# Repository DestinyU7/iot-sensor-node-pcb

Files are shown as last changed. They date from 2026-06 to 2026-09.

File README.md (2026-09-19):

# IoT Sensor Node — Custom Arduino Shield PCB

A two-layer PCB designed from scratch in KiCad, fabricated at JLCPCB, hand-assembled, and running firmware that publishes live temperature telemetry to a cloud dashboard over Wi-Fi.

## Overview

University of Delaware coursework: **ELEG 298, ECE Design Challenges (Spring 2025)**. My first board taken end to end — schematic capture through layout, design rule check, Gerber generation, fabrication order, assembly, and bring-up.

The board is an Arduino Uno shield carrying a DHT20 temperature/humidity sensor interface, an ESP-01S Wi-Fi module on a UART link, status LEDs, and the supporting passives. Firmware reads temperature, classifies the trend as rising, falling or stable, signals that trend on two LEDs, and publishes each reading to an Adafruit IO feed over Wi-Fi.

<p align="center">
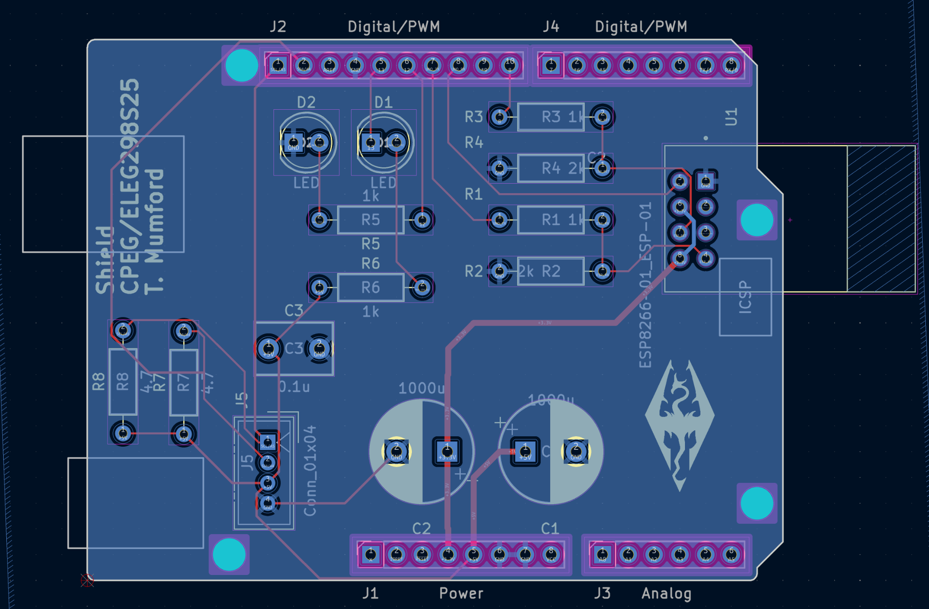
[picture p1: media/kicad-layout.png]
KiCad PCB layout
  
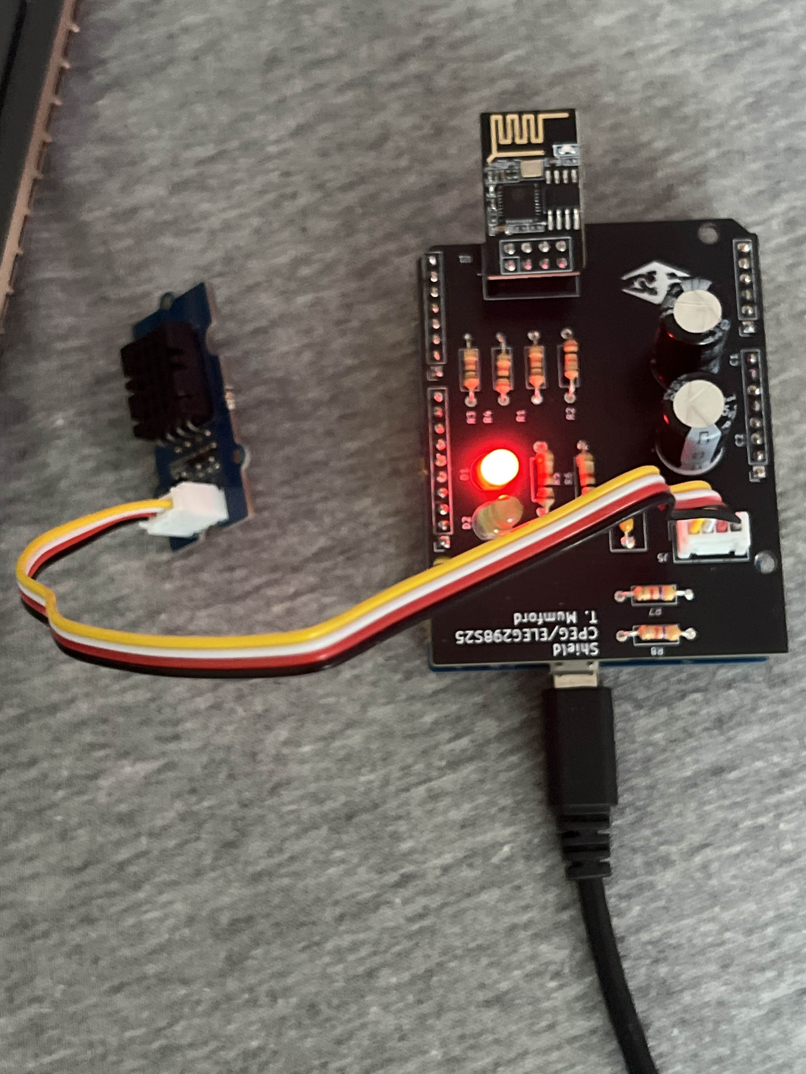
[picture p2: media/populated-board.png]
Fabricated board, hand-assembled and powered
  
</p>

<p align="center"><em>Left: the two-layer layout in KiCad. Right: the fabricated board hand-assembled, with the ESP-01S module fitted and a Grove sensor attached.</em></p>

## Hardware

| Function | Part |
|---|---|
| Host | Arduino Uno (shield form factor) |
| Wi-Fi | ESP-01S (ESP8266) over software UART |
| Sensor | DHT20 temperature / humidity (I²C, Grove connector) |
| Indicators | 2 × LED with 1 kΩ current-limiting resistors |
| Power | Bulk 1000 µF electrolytics + 0.1 µF decoupling |
| Level/pull-ups | 1 kΩ / 2 kΩ divider network, 4.7 kΩ I²C pull-ups |

Two copper layers (`F_Cu`, `B_Cu`), silkscreen on both sides, mounting holes, and an ICSP header passthrough.

## Software / Tools

- **KiCad** — schematic capture, PCB layout, DRC, Gerber and drill file export
- **Arduino C++** — `SoftwareSerial`, Grove DHT library
- **JLCPCB** — fabrication
- **Adafruit IO** — cloud feed and dashboard
- DigiKey-sourced BOM with costed line items

## Architecture

```mermaid
flowchart LR
    DHT["DHT20 sensor<br/>temperature + humidity"] -->|I2C| UNO
    UNO["Arduino Uno<br/>trend classifier"] -->|software UART<br/>9600 baud| ESP["ESP-01S<br/>ESP8266 Wi-Fi"]
    UNO --> LEDS["Red / green LEDs<br/>trend indication"]
    ESP -->|Wi-Fi| AIO["Adafruit IO<br/>temperature-feed"]
    AIO --> DASH["Cloud dashboard"]
```

The Uno drives the ESP-01S through a simple text command protocol over software serial (`wifi_ssid=`, `wifi_pass=`, `io_user=`, `io_key=`, `setup_io`, `setup_pubfeed=`, `send_data=`), with per-command timeouts and a hardware reset line to bring the module up cleanly at boot.

## Key Engineering Work

**Full PCB workflow, not just a schematic.** Component placement, two-layer routing with 45° trace angles and no right-angle bends, an 8 mil minimum line/space rule, silkscreen reference designators and polarity markers on both sides, DRC to zero errors and zero airwires, then Gerber + drill export and a fabrication-portal preview check before ordering. The Gerber set that was actually sent to the fab is in `hardware/gerbers/`.

**Designing for hand assembly.** The board mixes through-hole and SMD parts, with part choice and spacing driven by what could realistically be soldered by hand and reworked if wrong — a constraint that shaped the layout as much as the electrical requirements did.

**Trend classification instead of raw reporting.** Firmware compares each reading against the previous one with a ±0.1 °C tolerance band and tracks the last rising value, so the LEDs show direction of change rather than flickering on sensor noise, plus a stable-band indication between 22–24 °C.

**Reset sequencing.** The ESP-01S is held in reset at boot and released deliberately before any command is sent, which avoids the race where configuration commands are transmitted before the module's UART is listening.

## Testing / Validation

- **DRC and airwire check** in KiCad before Gerber export; fabrication-portal preview reviewed against the intended layout.
- **Continuity and power-rail checks** on the bare board before any active parts were fitted.
- **Incremental bring-up** — power, then LEDs, then sensor over I²C, then the ESP-01S link, then cloud publishing.
- **End-to-end verification** by watching readings appear on the Adafruit IO dashboard while warming the sensor by hand and confirming the LED trend indication matched.

## Repository Structure

```
firmware/           iot_sensor_node.ino - Arduino firmware
hardware/
  kicad/            schematic and two-layer board layout
  gerbers/          fabrication set sent to JLCPCB (copper, mask, silk, paste, drill)
docs/               final project design report
media/              layout render and photo of the assembled board
```

## Security Note

The Adafruit IO key and Wi-Fi credentials are **redacted** from the committed firmware (`IO_KEY = "REPLACE_WITH_ADAFRUIT_IO_KEY"`). Supply your own credentials to run it. No live key appears anywhere in this repository or its commit history.

## What I Learned

The layout was where the real learning was. A schematic that passes electrical rules can still be a board that is painful to assemble, hard to probe, and awkward to mount — trace angles, part spacing, silkscreen legibility and test-point access are decisions you only appreciate once you are holding the fabricated board with an iron in your hand.

Ordering it was the other half. Once Gerbers are submitted there is no undo, which forces a much more careful review pass than any purely simulated assignment ever did.

## Academic Context

University of Delaware, ELEG 298 — ECE Design Challenges, Spring 2025. Design, layout, firmware and assembly are my own work.

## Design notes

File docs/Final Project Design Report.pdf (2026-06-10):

### Final Project Design Report

### Timothy Mumford

5/16/2025

### 1. Description of the Circuit Functionality

For this project, I took the core of a Seeeduino and used it to build a custom PCB in KiCad. The main idea was to make a small device that could tell me if temperatures were getting too high while I was gaming on my PC. I used one of the sensors from the Grove kit (a temp sensor), and based on the readings, it lights up a red LED if things are getting too hot, and a green LED when things are normal. It's a pretty simple visual indicator but good enough to keep me aware without needing to check software every time.

This project helped me get familiar with PCB design, and I also learned how to integrate Grove connectors and keep the circuit small and functional.

### 2. Schematics of the Circuit

### See the attached schematic Png generated in KiCad. It shows all the components like the ESP8266 module, LEDs, resistors, and Grove connector. Everything was kept minimal to keep

the board compact.

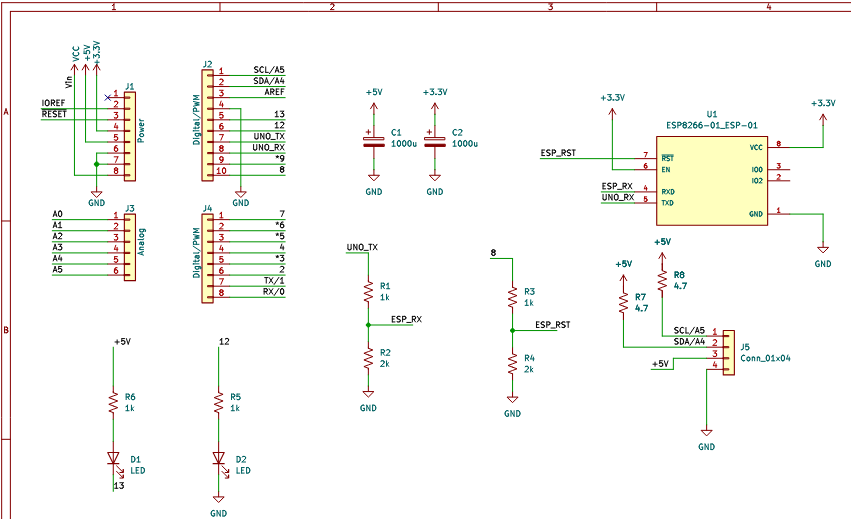
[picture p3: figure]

### 3. CAM Images (Manufacturing View)

### Top and bottom images of the PCB were exported from the KiCad 3D viewer. These show what

the finished board would look like. The layout was kept as neat as possible given the limited space.

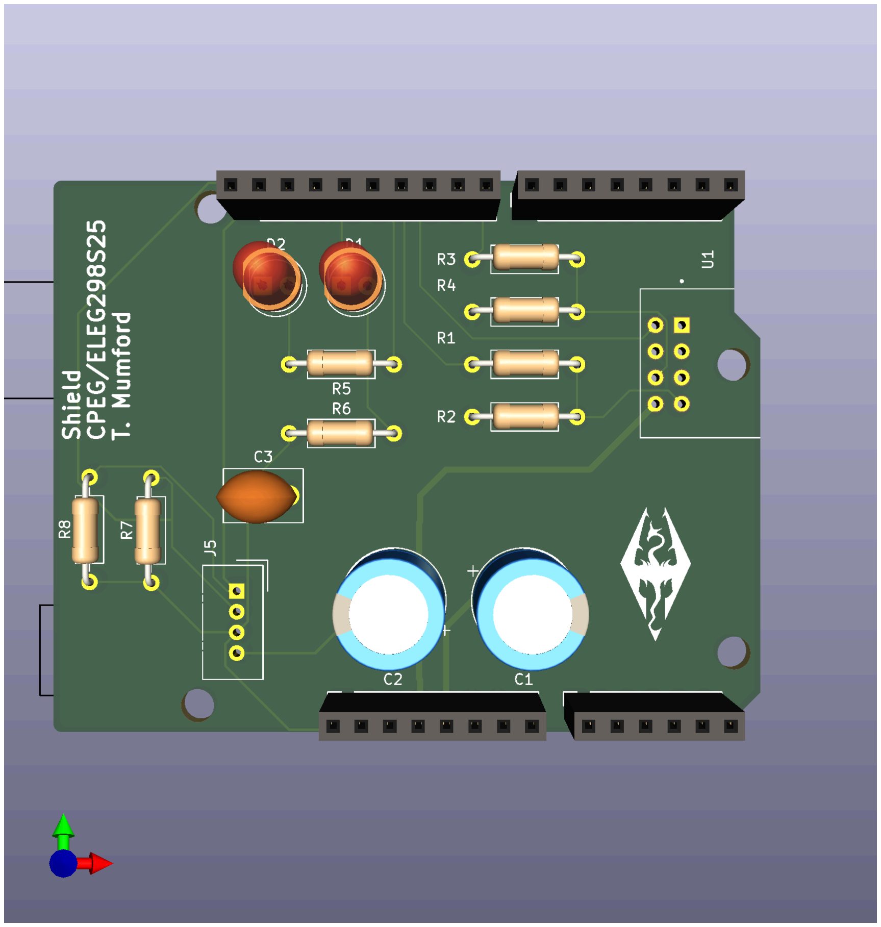
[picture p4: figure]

●

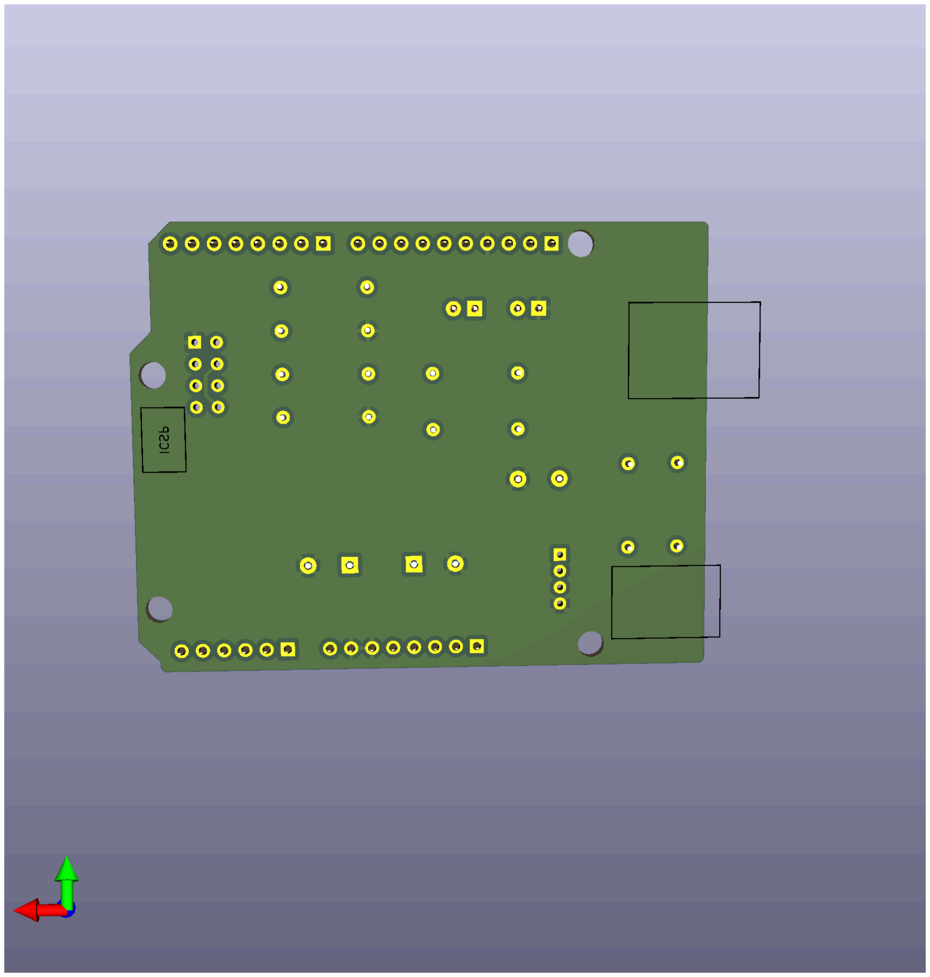
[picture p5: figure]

●

### 4. Bill of Materials (BOM)

Part | Value | Qty | Notes
ESP8266-01 | WiFi Module | 1 | Main microcontroller
R1, R3, R5, R6 | 1k Resistors | 4 | Used for pull-up / LED current limiting
R2, R4 | 2k Resistors | 2 | Divider or biasing
R7, R8 | 4.7 Ohm Resistors 2 | For LEDs
C1, C2 | 1000uF Capacitors 2 | Power filtering
D1, D2 | LEDs (Red, Green) 2 | Status indicators
Grove Connector 4-pin | 1 | Sensor input
Misc Headers | - | - | For power and GPIO access

All components were either from the Grove Starter Kit or standard through-hole parts.

### 5. Arduino Code Description

The code was written using the Arduino IDE and uses standard libraries. It reads temperature

### data from the Grove sensor. If the temp goes above a certain threshold (like 30 degrees

Celsius), it turns on the red LED. Otherwise, it stays green. I also added Adafruit IO support so it could upload the temp readings to the cloud.

### Libraries used:

## - ESP8266WiFi.h

## - AdafruitIO_WiFi.h

### 6. Adafruit IO Dashboard

A screenshot of the Adafruit IO dashboard is included. It graphs the temperature readings over time so I can look back and see if temps got too high while gaming.

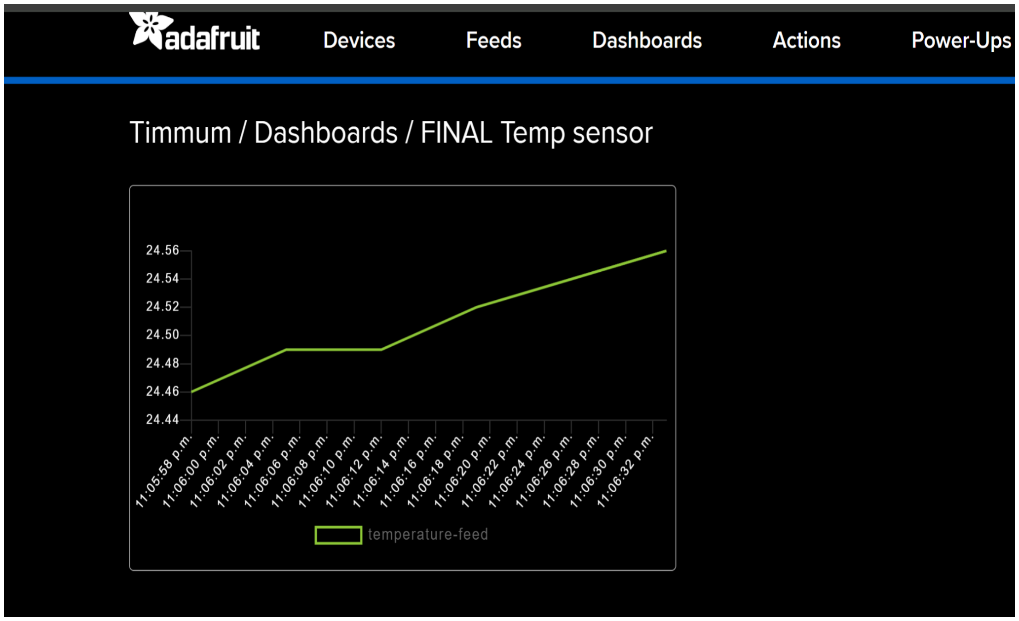
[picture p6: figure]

### 7. Design Improvements

If I were to do this project again, I’d try to redesign it so I could hook it straight to my PC’s

### motherboard for power. The whole reason I made this was so I could keep an eye on temps

while gaming, so if I could connect it to something like a USB header or internal 5V rail that’d be cleaner. That way I wouldn't need a separate cable or wall plug.

### 8. Appendix: Arduino Code

#include "Arduino.h"

#include <SoftwareSerial.h>

#include "Grove_Temperature_And_Humidity_Sensor.h"

#define RESET_PIN 8 | // pin used to bring ESP-01 module up in UART

mode
#define UART_TX_PIN 11 | // UART software serial transmit pin

#define UART_RX_PIN 10 | // UART software serial receive pin

#define DHTTYPE DHT20

#define DHTPIN 2

DHT dht(DHTPIN, DHTTYPE);

// LED pins
#define RED_LED_PIN 13

#define GREEN_LED_PIN 12

SoftwareSerial espSerial(UART_RX_PIN, UART_TX_PIN); // Create software UART to talk to the ESP8266
String IO_USERNAME = "Timmum";
String IO_KEY = "aio_yVXB53vtyaXUfBuhB20TLqv0Pang";
String WIFI_SSID = "UD Devices";
String WIFI_PASS = "";

float num = 1.0;
float lastTemperature = 0.0; float lastRiseTemp = 0.0;
const float TEMP_TOLERANCE = 0.1; const float STABLE_LOW = 22.0; const float STABLE_HIGH = 24.0; String response;
long int time;

void setup() {
Serial.begin(115200);
espSerial.begin(9600);
pinMode(RESET_PIN, OUTPUT); digitalWrite(RESET_PIN, LOW); delay(1000);
digitalWrite(RESET_PIN, HIGH);

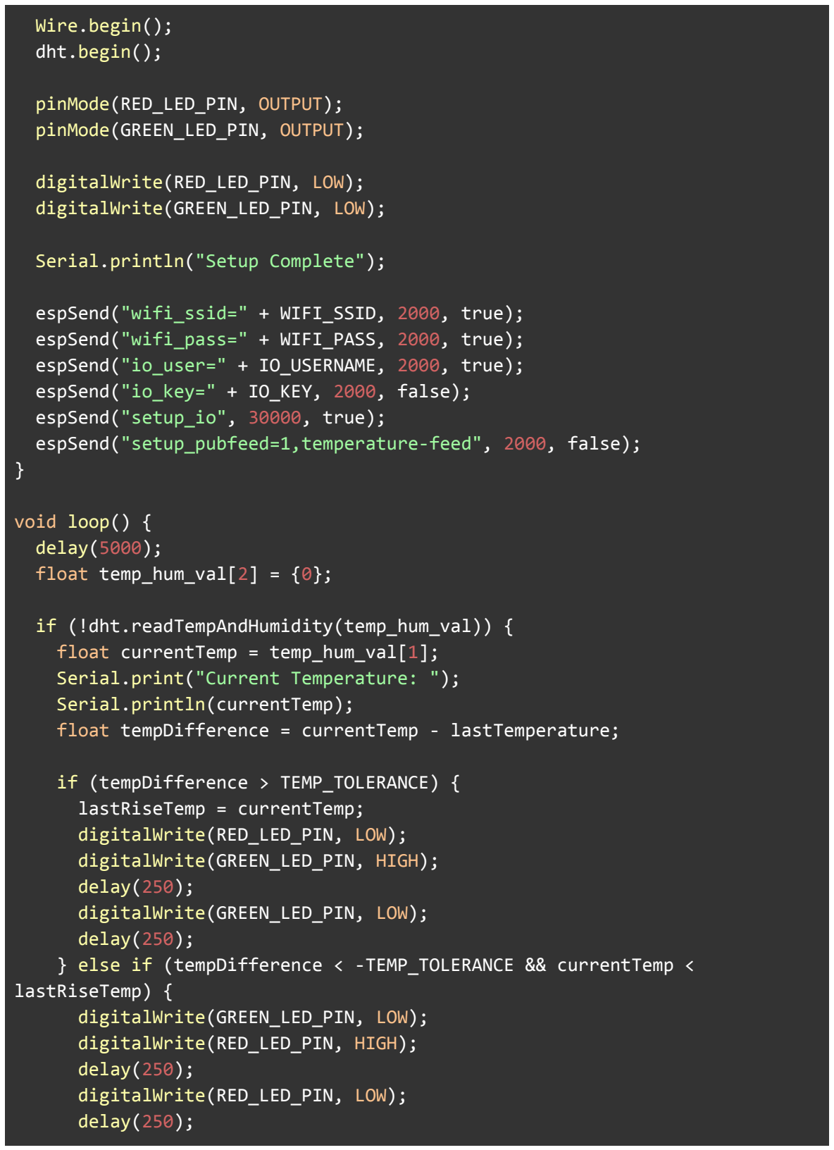
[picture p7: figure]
Wire.begin(); dht.begin();; pinMode(RED_LED_PIN, OUTPUT); pinMode(GREEN_LED_PIN, OUTPUT);; digitalWrite(RED_LED_PIN, LOW); digitalWrite(GREEN_LED_PIN, LOW);; Serial.println("Setup Complete");; espSend("setup_io", 30000, true);; void loop() { delay(5000); float temp_hum_val[2] = {0};; float currentTemp = temp_hum_val[1]; Serial.print("Current Temperature: "); Serial.println(currentTemp);; if (tempDifference > TEMP_TOLERANCE) { lastRiseTemp = currentTemp; digitalWrite(RED_LED_PIN, LOW); digitalWrite(GREEN_LED_PIN, HIGH); delay(250); digitalWrite(GREEN_LED_PIN, LOW); delay(250);; lastRiseTemp) { digitalWrite(GREEN_LED_PIN, LOW); digitalWrite(RED_LED_PIN, HIGH); delay(250); digitalWrite(RED_LED_PIN, LOW); delay(250);

espSend("wifi_ssid=" + WIFI_SSID, 2000, true); espSend("wifi_pass=" + WIFI_PASS, 2000, true); espSend("io_user=" + IO_USERNAME, 2000, true); espSend("io_key=" + IO_KEY, 2000, false);

espSend("setup_pubfeed=1,temperature-feed", 2000, false);

if (!dht.readTempAndHumidity(temp_hum_val)) {

float tempDifference = currentTemp - lastTemperature;

} else if (tempDifference < -TEMP_TOLERANCE && currentTemp <

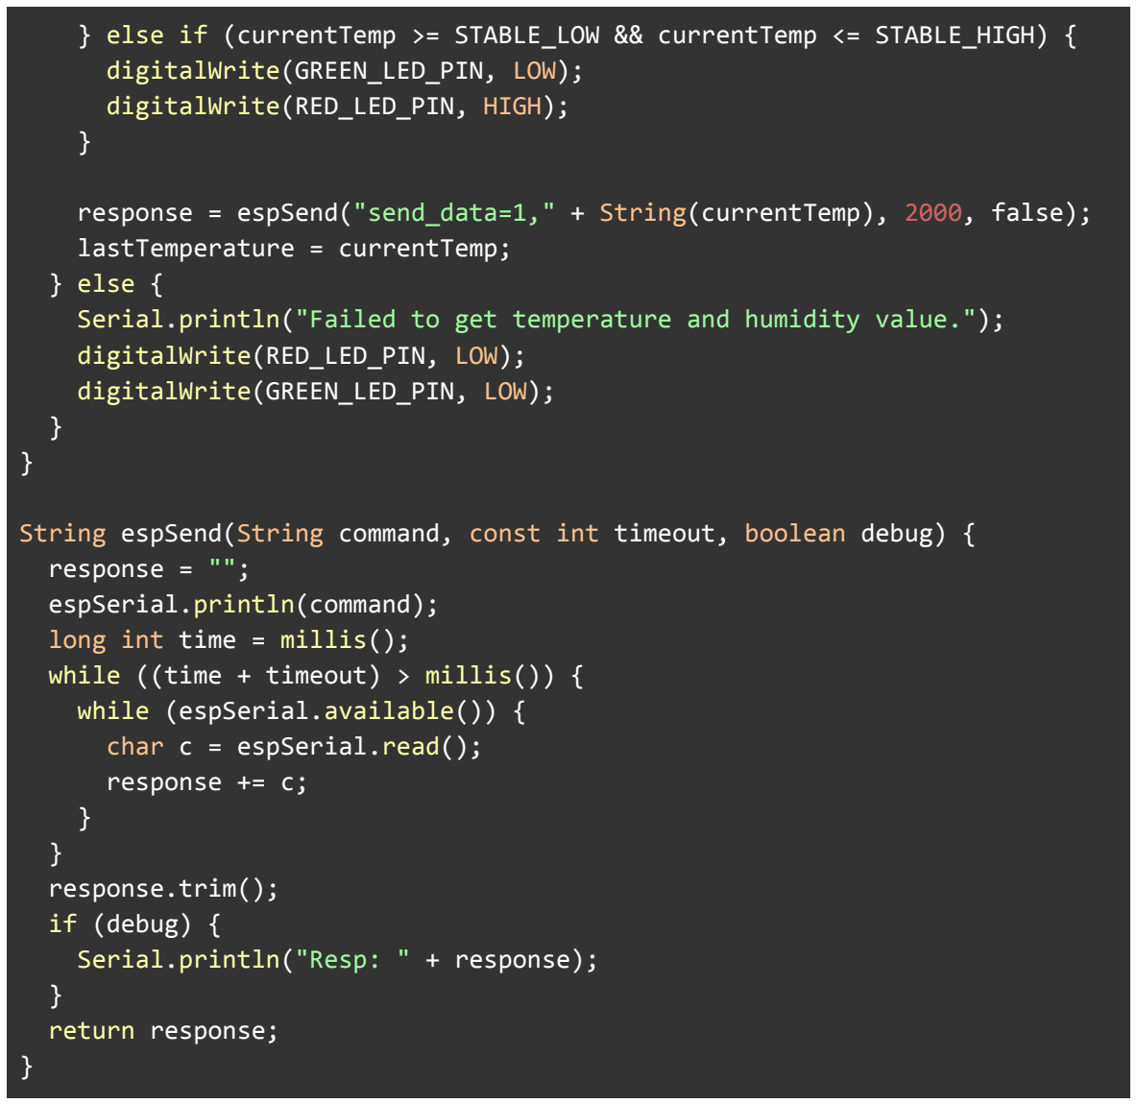
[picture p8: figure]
digitalWrite(GREEN_LED_PIN, LOW); digitalWrite(RED_LED_PIN, HIGH);; lastTemperature = currentTemp; } else {; digitalWrite(RED_LED_PIN, LOW); digitalWrite(GREEN_LED_PIN, LOW);; response = ""; espSerial.println(command); long int time = millis(); while ((time + timeout) > millis()) { while (espSerial.available()) { char c = espSerial.read(); response += c;; } response.trim(); if (debug) { Serial.println("Resp: " + response);; } return response;

} else if (currentTemp >= STABLE_LOW && currentTemp <= STABLE_HIGH) {

response = espSend("send_data=1," + String(currentTemp), 2000, false);

Serial.println("Failed to get temperature and humidity value.");

String espSend(String command, const int timeout, boolean debug) {

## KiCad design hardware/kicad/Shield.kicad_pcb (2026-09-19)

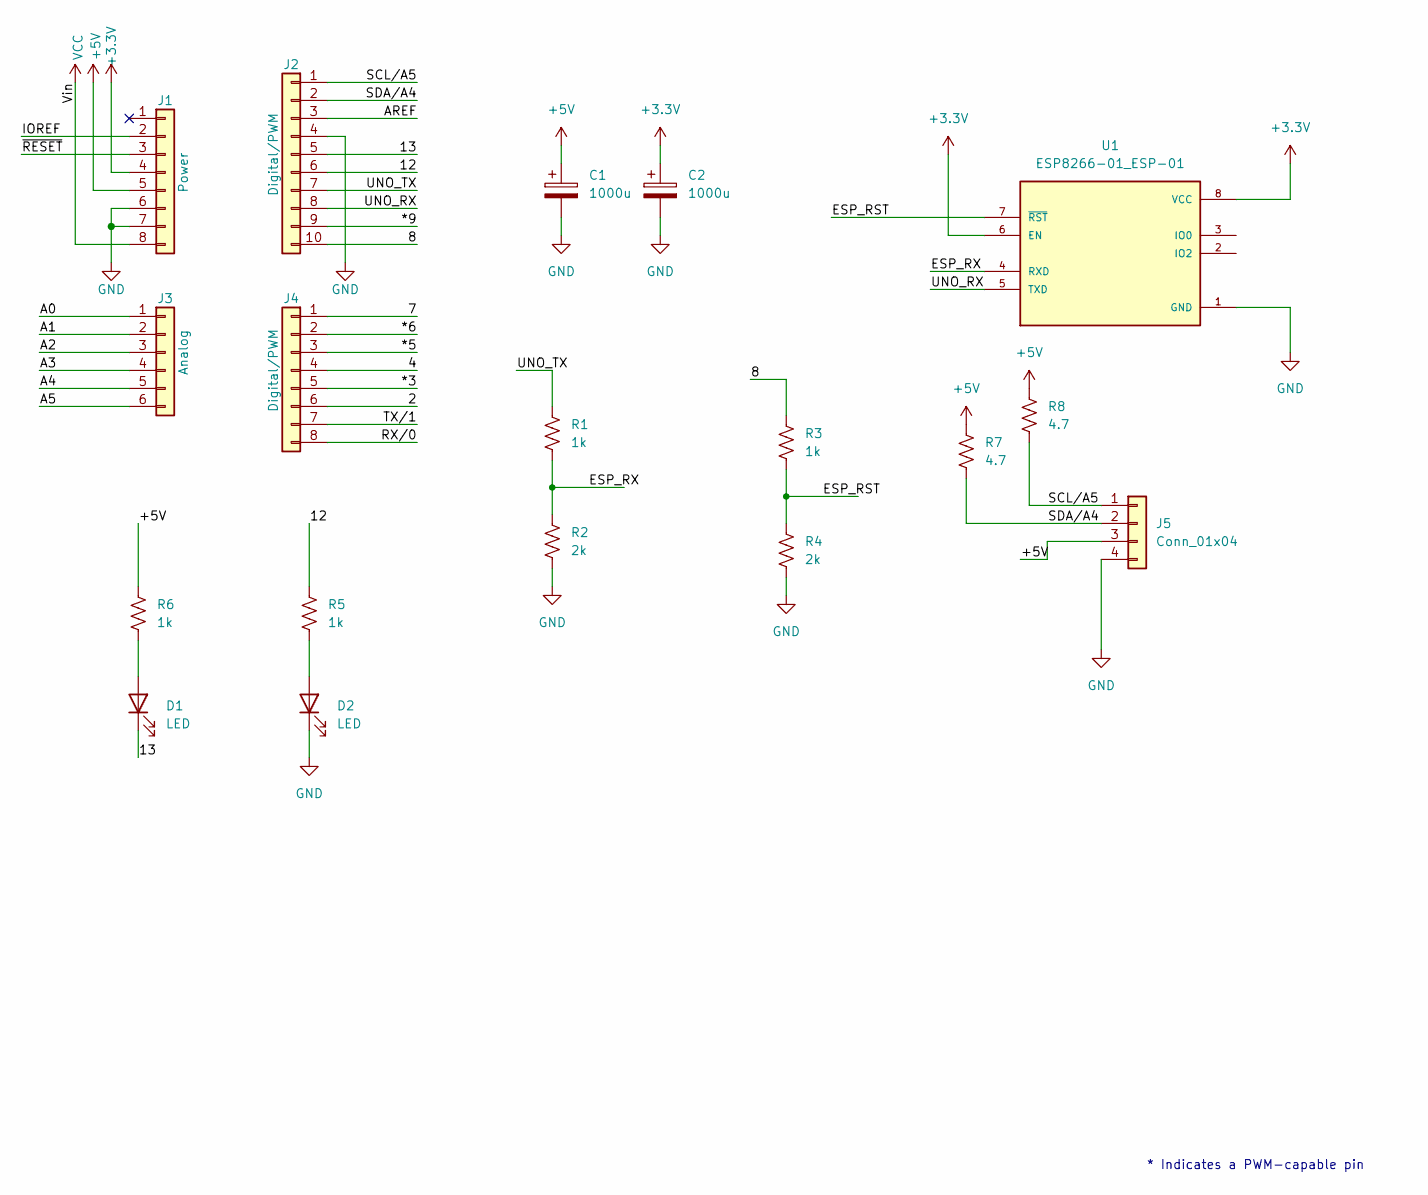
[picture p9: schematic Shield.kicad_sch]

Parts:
C1, C2: 1000u; CP_Radial_D10.0mm_P5.00mm
D1, D2: LED; LED_D5.0mm
J1: Power; PinSocket_1x08_P2.54mm_Vertical
J2: Digital/PWM; PinSocket_1x10_P2.54mm_Vertical
J3: Analog; PinSocket_1x06_P2.54mm_Vertical
J4: Digital/PWM; PinSocket_1x08_P2.54mm_Vertical
J5: Conn_01x04; NS-Tech_Grove_1x04_P2mm_Vertical
R1, R3, R5, R6: 1k; R_Axial_DIN0207_L6.3mm_D2.5mm_P10.16mm_Horizontal
R2, R4: 2k; R_Axial_DIN0207_L6.3mm_D2.5mm_P10.16mm_Horizontal
R7, R8: 4.7; R_Axial_DIN0207_L6.3mm_D2.5mm_P10.16mm_Horizontal
U1: ESP8266-01_ESP-01; XCVR_ESP8266-01_ESP-01; PARTREV V1.2

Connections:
+3.3V: C2.1, J1.4, U1.6 (EN), U1.8 (VCC)
+5V: C1.1, J1.5, J5.3, R6.1, R7.1, R8.1; also elsewhere on the board
/2: J4.6
/4: J4.4
/7: J4.1
/8: J2.10, R3.1
/12: J2.6, R5.1
/13: D1.1 (K), J2.5
/*3: J4.5
/*5: J4.3
/*6: J4.2
/*9: J2.9
/A0: J3.1
/A1: J3.2
/A2: J3.3
/A3: J3.4
/A4: J3.5
/A5: J3.6
/AREF: J2.3
/ESP_RST: R3.2, R4.1, U1.7 (~RST)
/ESP_RX: R1.2, R2.1, U1.4 (RXD)
/IOREF: J1.2
/RX/0: J4.8
/SCL/A5: J2.1, J5.1, R8.2
/SDA/A4: J2.2, J5.2, R7.2
/TX/1: J4.7
/UNO_RX: J2.8, U1.5 (TXD)
/UNO_TX: J2.7, R1.1
/~RESET: J1.3
GND: C1.2, C2.2, D2.1 (K), J1.6, J1.7, J2.4, J5.4, R2.2, R4.2, U1.1 (GND); also elsewhere on the board
unnamed: D1.2 (A), R6.2
unnamed: D2.2 (A), R5.2
VCC: J1.8

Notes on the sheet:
* Indicates a PWM-capable pin

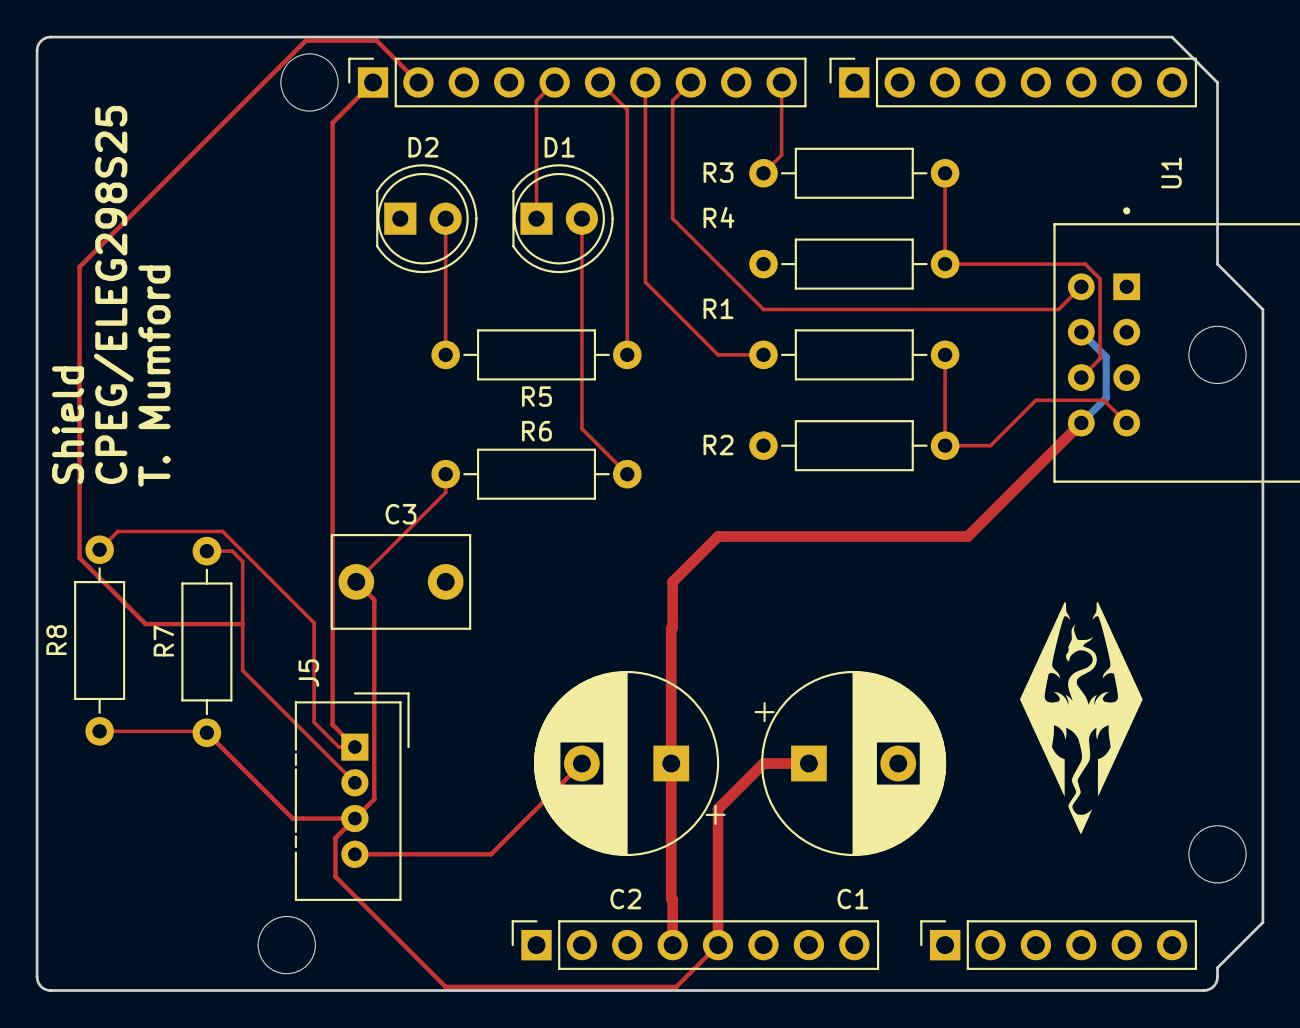
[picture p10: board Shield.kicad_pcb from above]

Board: 2 copper layers, 68.6 x 53.3 mm, 23 parts (0 on the bottom side), 14 nets.

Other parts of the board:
C3: 0.1u; C_Disc_D7.5mm_W5.0mm_P5.00mm
MH1, MH2, MH3, MH4: MountingHole_3.2mm

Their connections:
+5V: C3.1; also elsewhere on the board
GND: C3.2; also elsewhere on the board
